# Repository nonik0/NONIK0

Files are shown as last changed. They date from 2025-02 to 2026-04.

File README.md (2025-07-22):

# Nick's Original Name Indicator Knicknack (version 0)

## Overview

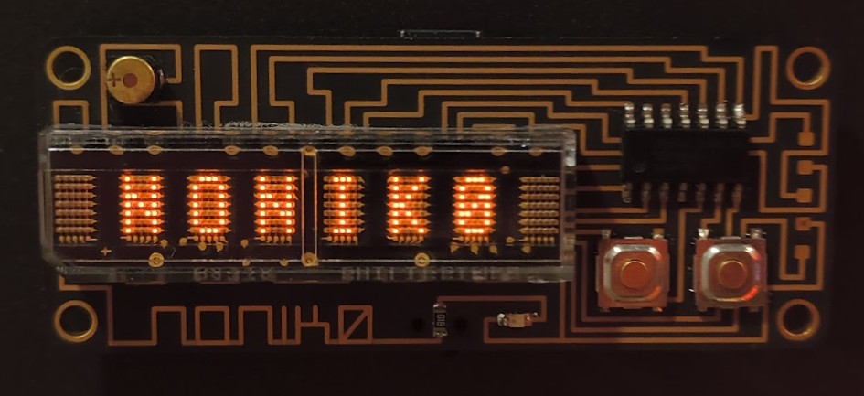
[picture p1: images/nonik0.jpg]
Front of NONIK0 board powered on and showing NONIK0 on display


It's a knicknack to indicate your name with the original design by me, Nick. Version 0. NONIK0 for short! The only version there will ever be. I wanted a name badge to wear sometimes and most other times just use for a fancy LED decoration, and also learn some more Rust. Add in a tad of scope creep and you have also have some games, beeps, and other extras, too. For more detail, I have a [project writeup](https://altonimb.us/nonik0/) where I talk about my process of completing this project start to finish, with more of a focus my experience working with Rust.

### Hardware
The hardware is designed in KiCad 8.0 and all design files are included in the [hardware/kicad8.0](hardware/kicad8.0) directory.

The main hardware components are:
- [HCMS-2914](https://www.broadcom.com/products/leds-and-displays/smart-alphanumeric-displays/serial-interface/hcms-2914) 5x7 dot matrix character display
- [ATtiny1604](https://www.microchip.com/en-us/product/attiny1604) 8-bit MCU
- [CMT-322-65-SMT-TR](https://www.digikey.com/en/products/detail/same-sky-formerly-cui-devices/CMT-322-65-SMT-TR/14682617) Piezo Buzzer 3.2mm x 3.2mm
- 2x [PTS526SMG](https://www.digikey.com/en/products/detail/c-k/PTS526SMG15JSMTR2-LFS/10056629) SPST push buttons

Revision #1:
- Swapped test pads and UPDI pads. The UPDI pads were opposite of the buzzer, which made getting the probe clip to remain clipped over the pads with the buzzer in the way more difficult than it needed to be.
- Added solder jumper to HCMS-291x SEL pin. Can optionally cut jumper to Vcc and solder other side to ground to use external oscillator for display.
- Optimized some routing for power and ground.

Revision #2:
- Fixed I2C pin assignment for external JST-SH connector
- Added piezo driver circuit

### Firmware

The firmware is written in Rust and can be found in the [firmware/rust](firmware/rust) directory. As part of the work, I wrote a new [HCMS-29xx driver](https://github.com/nonik0/hcms-29xx) and forked avr-hal to add a Feather32u4 support, which I used for bootstrapping the HCMS-29xx driver work. There is also an older PlatformIO project targetting the Adafruit Feather in the [firmware/cpp](firmware/cpp) directory.

The firmware is navigated using two buttons. Navigation and control is done with the two push buttons. A short press on the right button is a "next" action and will show the next option in the current context (i.e. the menu or active mode). A short press on the left button depends on the given context, and is either a "previous" action or a "alternate" action. A long press on the right button is an "enter/confirm" action and will enter a mode from the menu or, from within a mode, change the current page or enter a submenu. A long press on the left button will do an "exit" action which exits from a mode to the menu, or exits from a submenu from a mode.

#### Modes

- **Name:** The original inspiration for this project. Displays an 8 character name (or other string). Can enter an edit mode to update the name/value and is persisted in EEPROM.
- **Settings:** Change the current max brightness and max current settings for HCMS-29XX display, in addition to toggling the button tones on or off.
- **Vibes:** Inspired from the prototype's zigzag pattern I used for testing scrolling/smoothness. It reminded me of watching mountains pass by from a train windows, so I added this mode with mountains and clouds with a parallax effect. The speed of the clouds and mountains can be changed with buttons.
- **Sensors:** The first of the scope creep feartures. Uses the ADC and can read various channels includes the internal temperature and references voltage, but primary the external voltage on the external JUST port pins for use as a simple voltmeter. Has a settings page where the various ADC parameter can be alterned, I used this for my own learning and understanding of the ADC parameters when implementing.
- **Random:** A simple mode that has several pages to display random values for use as a decision tool: integer values, dice values, "eight ball" yes/maybe/no values, and random cuisine types.
- **Tunnel** A basic tunnel game where you control a runner that moves up/down with left/right buttons and you try to survive as long as possible as the tunnel shrinks.
- **Traffic** Another basic game where a you control a driver that advances to the right as you avoid other traffic (rectangles) progressing to the left.

## Design Images

<p align="center" width="100%">
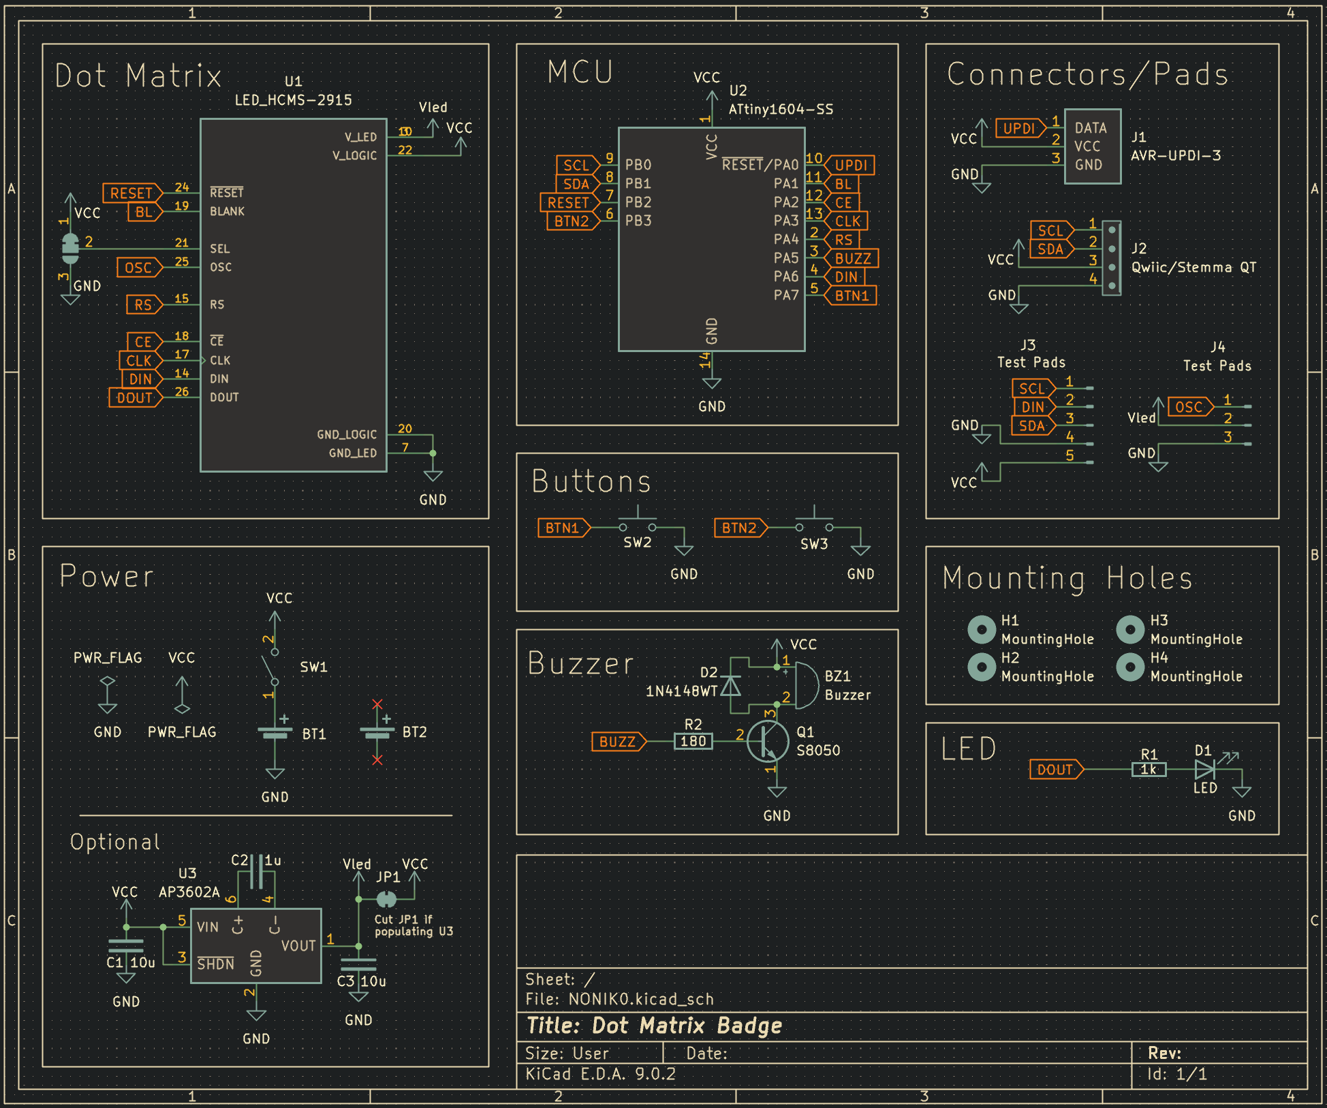
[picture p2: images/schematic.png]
  
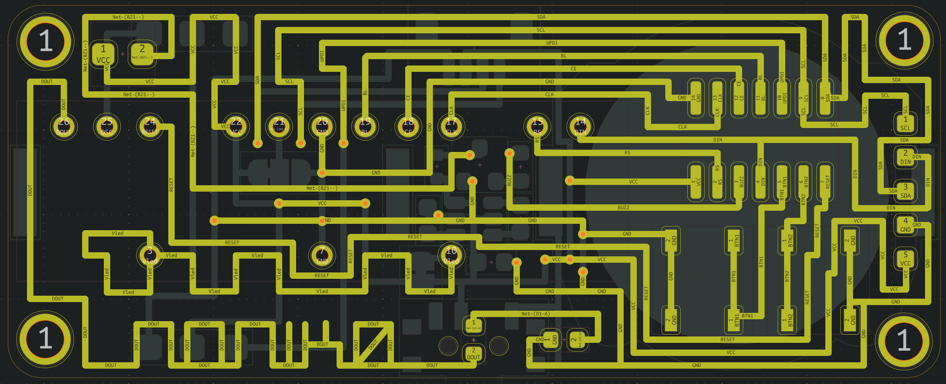
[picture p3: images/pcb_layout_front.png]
  
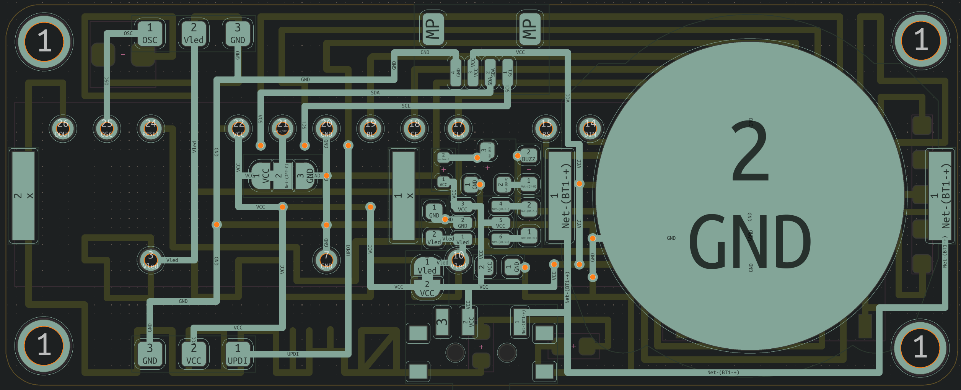
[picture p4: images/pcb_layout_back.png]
  
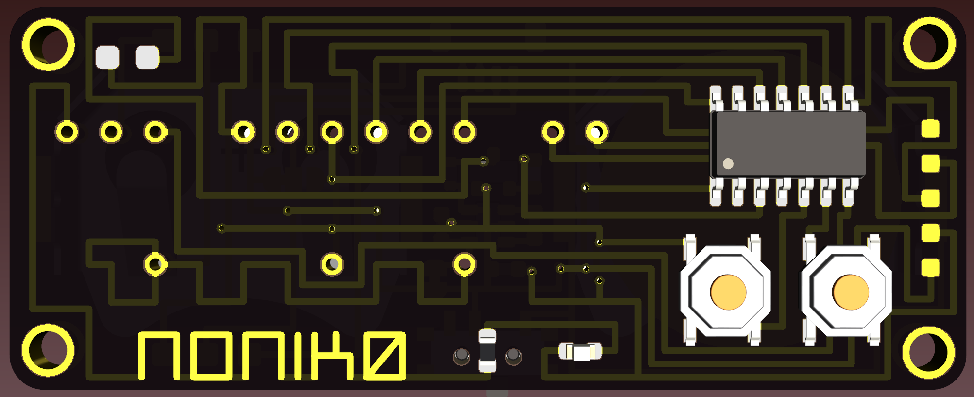
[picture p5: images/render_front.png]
  
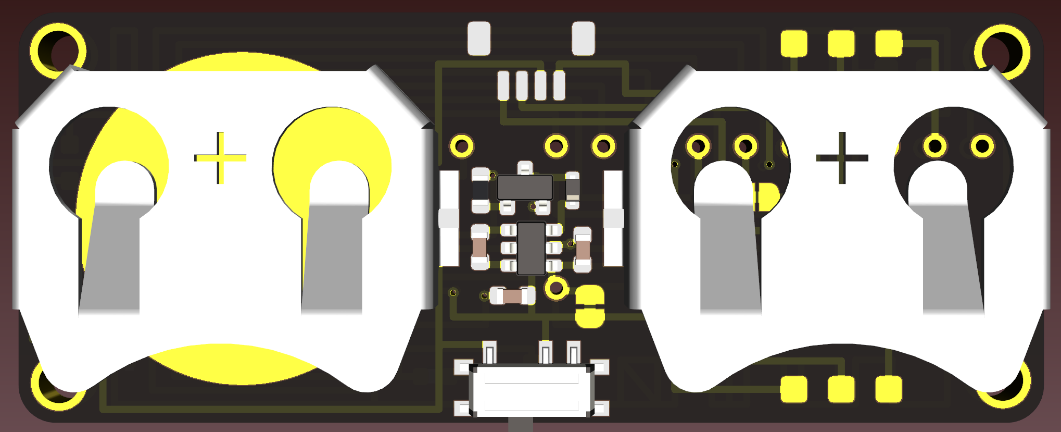
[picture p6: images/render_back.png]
  
</p>

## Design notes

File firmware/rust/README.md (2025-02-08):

NONIK0
==========

Rust project for the _Arduino Leonardo_.

## Build Instructions
1. Install prerequisites as described in the [`avr-hal` README] (`avr-gcc`, `avr-libc`, `avrdude`, [`ravedude`]).

2. Run `cargo build` to build the firmware.

3. Run `cargo run` to flash the firmware to a connected board.  If `ravedude`
   fails to detect your board, check its documentation at
   <https://crates.io/crates/ravedude>.

4. `ravedude` will open a console session after flashing where you can interact
   with the UART console of your board.

[`avr-hal` README]: https://github.com/Rahix/avr-hal#readme
[`ravedude`]: https://crates.io/crates/ravedude

## License
Licensed under either of

 - Apache License, Version 2.0
   ([LICENSE-APACHE](LICENSE-APACHE) or <http://www.apache.org/licenses/LICENSE-2.0>)
 - MIT license
   ([LICENSE-MIT](LICENSE-MIT) or <http://opensource.org/licenses/MIT>)

at your option.

## Contribution
Unless you explicitly state otherwise, any contribution intentionally submitted
for inclusion in the work by you, as defined in the Apache-2.0 license, shall
be dual licensed as above, without any additional terms or conditions.

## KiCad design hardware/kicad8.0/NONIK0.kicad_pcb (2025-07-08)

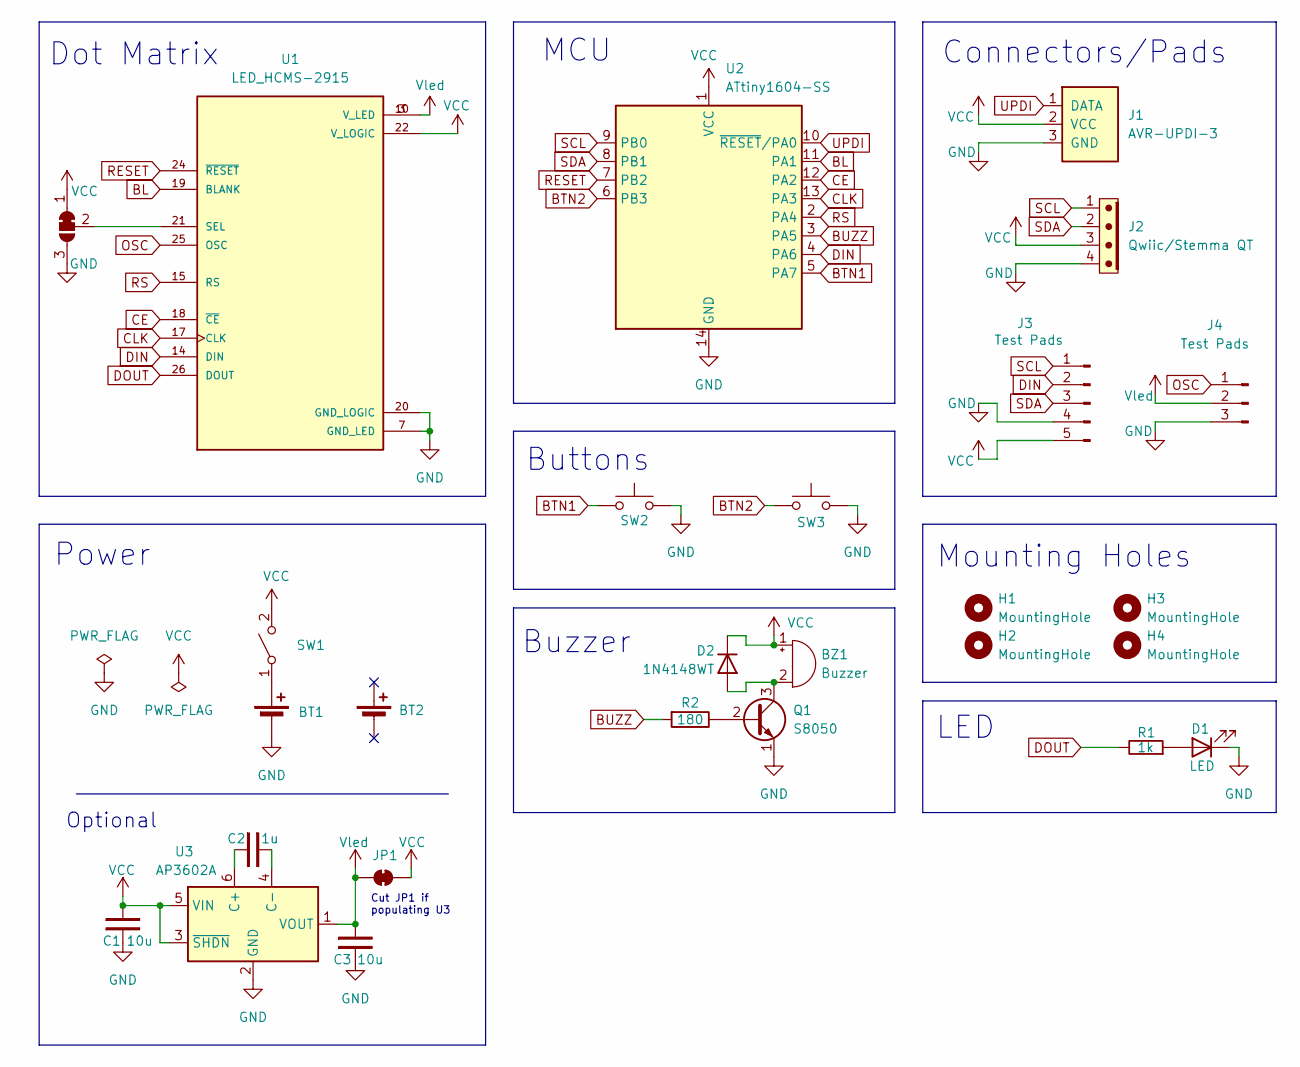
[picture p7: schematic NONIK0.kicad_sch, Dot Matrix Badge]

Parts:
BT1: Battery_Cell; BatteryHolder_Keystone_3034_1x20mm
BT2: Battery_Cell; SpareBatteryHolder_Keystone_3034_1x20mm
BZ1: Buzzer; CMT-322-65-SMT-TR
C1, C3: 10u; C_0603_1608Metric
C2: 1u; C_0603_1608Metric
D1: LED; LED_0603_1608Metric
D2: 1N4148WT; D_SOD-523_NoSilkscreen
H1, H2, H3, H4: MountingHole; MountingHole_Custom
J1: AVR-UPDI-3; Pads_1x3_2.54mm
J2: Qwiic/Stemma QT; JST_SH_4P_No Silkscreen
J3: Test Pads; Pads_1x5_1mm
J4: Test Pads; Pads_1x3_2.54mm
JP1: SolderJumper_2_Bridged; SolderJumper_SmallerFootprint
JP2: SolderJumper_3_Bridged12; SolderJumper-3_P1.3mm_Bridged12_RoundedPad1.0x1.5mm
Q1: S8050; SOT-23-SmallerCourtyard
R1: 1k; R_0603_1608Metric
R2: 180; R_0603_1608Metric
SW1: SW_SPST; SW_SPDT_PCM12
SW2, SW3: SW_Push; SW_SPST_PTS526_JLeads
U1: LED_HCMS-2915; HCMS-291X; PARTREV N/A
U2: ATtiny1604-SS; SOIC-14_3.9x8.7mm_P1.27mm
U3: AP3602A; SOT-23-6_SmallerFootprint

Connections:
BL: U1.19 (BLANK), U2.11 (PA1)
BTN1: SW2.1, U2.5 (PA7)
BTN2: SW3.1, U2.6 (PB3)
BUZZ: R2.2, U2.3 (PA5)
CE: U1.18 (~CE), U2.12 (PA2)
CLK: U1.17 (CLK), U2.13 (PA3)
DIN: J3.2, U1.14 (DIN), U2.4 (PA6)
DOUT: R1.2, U1.26 (DOUT)
GND: BT1.2 (-), C1.1, C3.1, D1.1 (K), J1.3 (GND), J2.4, J3.4, J4.3, JP2.3 (B), Q1.1 (E), SW2.2, SW3.2, U1.7 (GND_LED), U1.20 (GND_LOGIC), U2.14 (GND), U3.2 (GND)
unnamed: BT1.1 (+), SW1.1 (A)
unnamed: BZ1.2 (-), D2.2 (A), Q1.3 (C)
unnamed: D1.2 (A), R1.1
unnamed: JP2.2 (C), U1.21 (SEL)
unnamed: Q1.2 (B), R2.1
unnamed: C2.1, U3.6 (C+)
unnamed: C2.2, U3.4 (C-)
OSC: J4.1, U1.25 (OSC)
RESET: U1.24 (~RESET), U2.7 (PB2)
RS: U1.15 (RS), U2.2 (PA4)
SCL: J2.1, J3.1, U2.9 (PB0)
SDA: J2.2, J3.3, U2.8 (PB1)
UPDI: J1.1 (DATA), U2.10 (~RESET/PA0)
VCC: BZ1.1 (+), C1.2, D2.1 (K), J1.2 (VCC), J2.3, J3.5, JP1.2 (B), JP2.1 (A), SW1.2 (B), U1.22 (V_LOGIC), U2.1 (VCC), U3.3 (~SHDN), U3.5 (VIN)
Vled: C3.2, J4.2, JP1.1 (A), U1.3 (V_LED), U1.10 (V_LED), U3.1 (VOUT)

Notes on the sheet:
Cut JP1 if populating U3
Mounting Holes
LED
Optional
MCU
Buttons
Dot Matrix
Connectors/Pads
Power
Buzzer

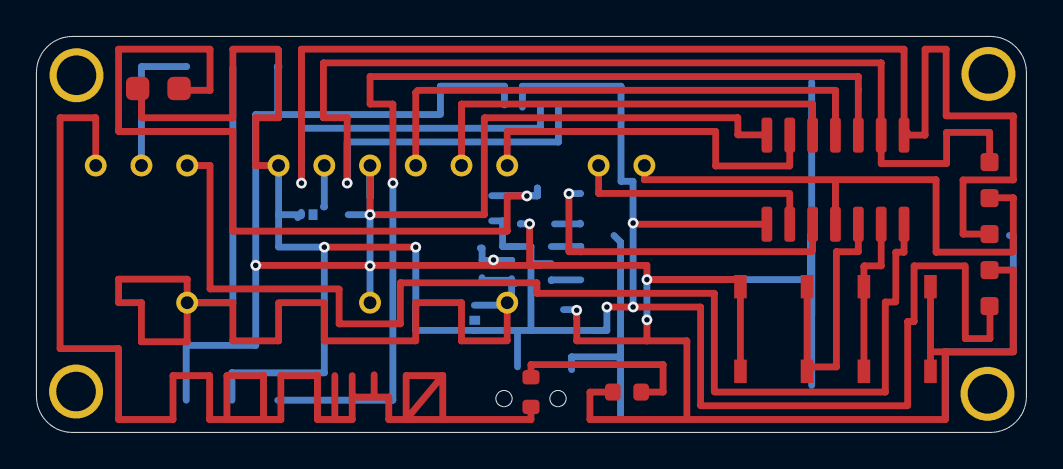
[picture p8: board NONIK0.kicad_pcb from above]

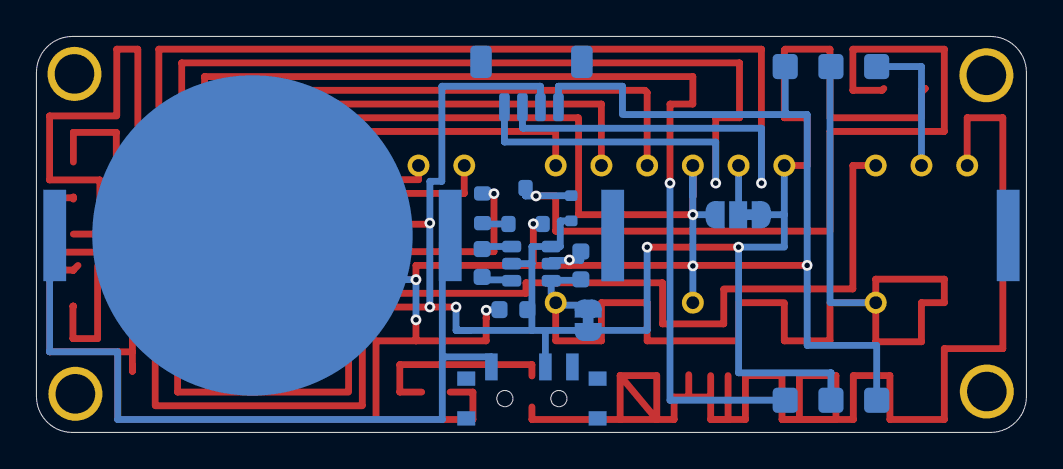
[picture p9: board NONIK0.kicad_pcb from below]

Board: 2 copper layers, 55.0 x 22.0 mm, 27 parts (15 on the bottom side), 24 nets.

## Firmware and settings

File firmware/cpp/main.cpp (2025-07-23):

#include "HCMS39xx.h"

#define NUM_CHARS 8

#ifdef ARDUINO_ARCH_MEGAAVR
#include <Wire.h>
// static pins:
// SEL: HIGH
#define DIN_PIN PIN_PA6 // 4
#define RS_PIN PIN_PA4  // 2
#define CLK_PIN PIN_PA3 // 13
#define CE_PIN PIN_PA2  // 12
#define BL_PIN PIN_PA1  // 11
#define SEL_PIN HCMS39xx::NO_PIN
// #define RESET_PIN PIN_PB0 // 9
#define RESET_PIN PIN_PB2 // 7

#define BTN1_PIN PIN_PA7 // 5
#define BTN2_PIN PIN_PB3 // 6

#define SDA_PIN PIN_PB1 // 8
// #define SCL_PIN PIN_PB2 // 7
#define SCL_PIN PIN_PB0 // 9

#define BUZZ_PIN PIN_PA5 // 3
#endif

#ifdef ARDUINO_AVR_FEATHER32U4
// static pins:
// 2: OSC: NC
// 8: BLANK: GND
// 10: SEL: HIGH
// 12: Reset: HIGH

// pin mappings feather proto:
// top display
// 7 | CE       | SDA/2
// 8 | BLANK    | SCL/3
// 9 | GND      | 5
// 10| SEL      | 6
// 11| Vlogic   | 9
// 12| Reset    | 10
// bottom display
// 1 | Data Out | SCK
// 2 | OSC      | MOSI
// 3 | Vled     | MISO
// 4 | Data In  | RX/0
// 5 | RS       | TX/1
// 6 | CLK      | GND (have to cut connection and route another pin)
#define DIN_PIN 0
#define RS_PIN 1
#define CLK_PIN 11
#define CE_PIN 2
#define BL_PIN 3
#define SEL_PIN 6
#define RESET_PIN 10

#define DOUT_PIN SCK
#define OSC_PIN MOSI

#define VLOGIC_PIN 9
#define VLED_PIN MISO
#define GND_PIN 5
#endif

#if defined(ARDUINO_ARCH_ESP32)
#define DIN_PIN 35
#define RS_PIN 37
#define CLK_PIN 36
#define CE_PIN 34
#define SEL_PIN HCMS39xx::NO_PIN
// missing pins
#endif

HCMS39xx hcms29xx(NUM_CHARS, DIN_PIN, RS_PIN, CLK_PIN, CE_PIN, BL_PIN, SEL_PIN);
uint8_t brightness = 0x0C;
HCMS39xx::DISPLAY_CURRENT current = HCMS39xx::CURRENT_4_0_mA;

void setup()
{
  Serial.begin(9600);

#if defined(RESET_PIN)
  pinMode(RESET_PIN, OUTPUT);
  digitalWrite(RESET_PIN, HIGH);
#endif

#if defined(ARDUINO_ARCH_MEGAAVR)
  Wire.begin();
  pinMode(BTN1_PIN, INPUT_PULLUP);
  pinMode(BTN2_PIN, INPUT_PULLUP);
#endif

#if defined(ARDUINO_AVR_FEATHER32U4)
  // put into high impedance
  pinMode(DOUT_PIN, INPUT);
  pinMode(OSC_PIN, INPUT);
  pinMode(VLOGIC_PIN, INPUT);
  pinMode(GND_PIN, INPUT);
#endif

  hcms29xx.begin();
  hcms29xx.displayUnblank();
  hcms29xx.setIntOsc();
  hcms29xx.setBrightness(brightness);
  hcms29xx.setCurrent(current);

  hcms29xx.print("I2C Scan");
  delay(1000);
}

uint32_t count1 = 0;
uint32_t count2 = 0;
void loop()
{
#if defined(ARDUINO_ARCH_MEGAAVR)
  /*
  if (digitalRead(BTN1_PIN) == LOW)
  {
    tone(BUZZ_PIN, 4000, 500);
    count1 = 0;

    brightness = (brightness + 1) % 16;
    hcms29xx.setBrightness(brightness);
    char buffer[10];
    snprintf(buffer, sizeof(buffer), "BRIGHT%02d", brightness);
    hcms29xx.print(buffer);
    delay(500);
  }
  if (digitalRead(BTN2_PIN) == LOW)
  {
    tone(BUZZ_PIN, 6000, 500);
    count2 = 0;

    if (current == HCMS39xx::CURRENT_4_0_mA)
    {
      current = HCMS39xx::CURRENT_6_4_mA;
      hcms29xx.print("CUR6.4mA");
    }
    else if (current == HCMS39xx::CURRENT_6_4_mA)
    {
      current = HCMS39xx::CURRENT_9_3_mA;
      hcms29xx.print("CUR9.3mA");
    }
    else if (current == HCMS39xx::CURRENT_9_3_mA)
    {
      current = HCMS39xx::CURRENT_12_8_mA;
      hcms29xx.print("CR12.8mA");
    }
    else if (current == HCMS39xx::CURRENT_12_8_mA)
    {
      current = HCMS39xx::CURRENT_4_0_mA;
      hcms29xx.print("CUR4.0mA");
    }
    hcms29xx.setCurrent(current);
    delay(500);
  }
  */
  hcms29xx.clear();
  hcms29xx.print("Scanning");
  delay(1000);

  for (byte address = 1; address < 127; address++)
  {
    Wire.beginTransmission(address);
    byte error = Wire.endTransmission();

    if (error == 0)
    {
      char buffer[10];
      snprintf(buffer, sizeof(buffer), "ACK:0x%02X", address);
      hcms29xx.clear();
      hcms29xx.print(buffer);
      delay(2000);
    }
  }

#else
  count1 = (count1 + 1) % 10000;

  if (random(0, 2) % 2 == 0)
  {
    count2 = (count2 + 1) % 10000;
  }

  // shift count1 4 decimal places to the left
  uint32_t displayNumber = count1 * 10000 + count2;
  hcms29xx.print(displayNumber);
#endif
  delay(5);
}

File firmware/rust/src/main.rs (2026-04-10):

#![no_std]
#![no_main]
#![feature(abi_avr_interrupt)]
#![feature(asm_experimental_arch)]
#![feature(type_alias_impl_trait)]

mod adc;
mod i2c;
mod input;
mod modes;
#[cfg(feature = "debug_panic")]
mod panic;
#[cfg(not(feature = "debug_panic"))]
use panic_halt as _;
mod random;
mod saved_settings;
mod tone;
mod utils;

use avrxmega_hal::eeprom::Eeprom;
use avrxmega_hal::port::{mode::Output, *};
use embedded_hal::delay::DelayNs;
use modes::*;
use random::Rand;

// using until proper ADC HAL implementation
type Adc0 = avrxmega_hal::pac::ADC0;
//type I2C = avrxmega_hal::pac::TWI0;
type Sigrow = avrxmega_hal::pac::SIGROW;
type Vref = avrxmega_hal::pac::VREF;
//type Adc = avrxmega_hal::adc::Adc<CoreClock>;
type CoreClock = avrxmega_hal::clock::MHz10;
type Delay = avrxmega_hal::delay::Delay<CoreClock>;
//type I2c = avrxmega_hal::i2c::I2c<CoreClock>;
#[cfg(feature = "board_v0")]
type Display = hcms_29xx::Hcms29xx<
    NUM_CHARS,
    Pin<Output, PA6>,
    Pin<Output, PA4>,
    Pin<Output, PA3>,
    Pin<Output, PA2>,
    Pin<Output, PA1>,
    hcms_29xx::UnconfiguredPin,
    Pin<Output, PB0>,
>;
#[cfg(not(feature = "board_v0"))]
type Display = hcms_29xx::Hcms29xx<
    NUM_CHARS,
    Pin<Output, PA6>,
    Pin<Output, PA4>,
    Pin<Output, PA3>,
    Pin<Output, PA2>,
    Pin<Output, PA1>,
    hcms_29xx::UnconfiguredPin,
    Pin<Output, PB2>,
>;
type DisplayPeakCurrent = hcms_29xx::PeakCurrent;
type Event = input::InputEvent;
type Setting = saved_settings::Setting;
type SavedSettings = saved_settings::SavedSettings;

// The virtual display size is larger to accomodate the physical gaps between characters.
// The const COLUMN_GAP is the number of "empty" columns between characters and will set
// the NUM_VIRT_COLS value, the virtual "width" of the display. During display
// updates, specific columns are dropped/skipped to create final NUM_COLS-wide display buffer.
const NUM_CHARS: usize = 8;
const NUM_ROWS: usize = hcms_29xx::CHAR_HEIGHT;
const NUM_COLS: usize = hcms_29xx::CHAR_WIDTH * NUM_CHARS;
const NUM_VIRT_COLS: usize = NUM_COLS + (NUM_CHARS - 1) * COLUMN_GAP;
const COLUMN_GAP: usize = 2;

const BASE_DELAY_MS: u32 = 5;

#[avr_device::entry]
fn main() -> ! {
    let dp = avrxmega_hal::Peripherals::take().unwrap();
    let pins = avrxmega_hal::pins!(dp);

    let mut buttons =
        input::Buttons::new(pins.pa7.into_pull_up_input(), pins.pb3.into_pull_up_input());
    let mut delay = Delay::new();

    let mut adc = adc::Adc::new(dp.ADC0, dp.SIGROW, dp.VREF);
    adc.seed_rand();

    #[cfg(not(feature = "no_i2cutils"))]
    let i2c = i2c::I2c::new(
        dp.TWI0,
        pins.pb1.forget_imode(),
        pins.pb0.forget_imode(),
    );

    let eeprom = Eeprom::new(dp.NVMCTRL);
    let settings = saved_settings::SavedSettings::new(eeprom);
    let buzzer = tone::Tone::new(dp.TCB0, pins.pa5.into_output());
   
    let mut display = Display::new(
        pins.pa6.into_output(),
        pins.pa4.into_output(),
        pins.pa3.into_output(),
        pins.pa2.into_output(),
        pins.pa1.into_output(),
        hcms_29xx::UnconfiguredPin,
        #[cfg(feature = "board_v0")]
        pins.pb0.into_output(),
        #[cfg(not(feature = "board_v0"))]
        pins.pb2.into_output(),
    )
    .unwrap();
    display.begin().unwrap();
    display.display_unblank().unwrap();

    let mut context = Context::new(settings);
    let mut peripherals = Peripherals::new(
        adc,
        buzzer,
        display,
        #[cfg(feature = "board_v0")]
        pins.pb1.forget_imode(),
        #[cfg(not(feature = "no_i2cutils"))]
        i2c,
    );

    // TODO: improve, apply saved display settings
    let settings = Settings::new_with_settings(&context.settings);
    settings.apply(&mut peripherals.display);

    // initialize default/saved mode
    let mut mode = Mode::from_context(&context);
    let mut mode_index = context.mode_index();
    loop {
        let event = buttons.update();

        match event {
            // special case to get always get back to menu
            Some(Event::BothHeld) => {
                if !context.is_menu() {
                    context.to_menu();
                }
            }
            // higher/shorter tone on button press
            Some(Event::LeftPressed) | Some(Event::RightPressed) => {
                if context.tone_enabled {
                    peripherals.buzzer.tone(5000, 5);
                }
            }
            // lower/longer tone on button held press
            Some(Event::LeftHeld) | Some(Event::RightHeld) => {
                if context.tone_enabled {
                    peripherals.buzzer.tone(4000, 10);
                }
            }
            _ => {}
        }

        // change mode when requested
        if mode_index != context.mode_index() {
            mode_index = context.mode_index();
            mode = Mode::from_context(&context);
        }

        mode.update(&event, &mut context, &mut peripherals);

        delay.delay_ms(BASE_DELAY_MS);
    }
}

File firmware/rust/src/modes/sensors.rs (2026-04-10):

use super::ModeHandler;
use crate::{
    adc::*, impl_enum_cycle, utils::*, Context, Event, Peripherals, SavedSettings, Setting,
    NUM_CHARS,
};

pub const RESOLUTION_VALUES: [u16; 2] = [10, 8]; // 2^10 - 1, 2^8 - 1
                                                 //pub const SAMPLE_NUMBER_DIVISORS: [u16; 7] = [1, 2, 4, 8, 16, 32, 64];
pub const PRESCALER_VALUES: [u16; 8] = [2, 4, 8, 16, 32, 64, 128, 256];
pub const INIT_DELAY_VALUES: [u16; 6] = [0, 16, 32, 64, 128, 256];
pub const INT_REF_VOLTAGE_STRINGS: [&[u8]; 5] = [b"0.55V", b"1.1V", b"2.5V", b"4.34V", b"1.5V"];
pub const VDD_REF_VOLTAGE_STRING: &[u8] = b"Vdd";
pub const BOOL_STRINGS: [&[u8]; 2] = [b" no", b"yes"];

#[cfg(not(feature = "board_v0"))]
pub const CONTINUITY_BLUE_READING_MASK: u16 = 0x0001;
#[cfg(not(feature = "board_v0"))]
pub const CONTINUITY_YELLOW_READING_MASK: u16 = 0x0002;
#[cfg(not(feature = "board_v0"))]
pub const CONTINUITY_BOTH_READING_MASK: u16 = 0x0003;

#[derive(Clone, Copy)]
pub enum SensorPage {
    AdcChannel(AdcChannel),
    ContinuityTest,
}

impl SensorPage {
    pub fn next(&self) -> Self {
        match self {
            SensorPage::AdcChannel(channel) => {
                let next_channel = channel.next_wrapping();
                if next_channel.to_u8() != 0 {
                    SensorPage::AdcChannel(next_channel)
                } else {
                    SensorPage::ContinuityTest
                }
            }
            SensorPage::ContinuityTest => SensorPage::AdcChannel(AdcChannel::from_u8(0)),
        }
    }
}

impl From<u8> for SensorPage {
    fn from(value: u8) -> Self {
        match value {
            1..=AdcChannel::COUNT => SensorPage::AdcChannel(AdcChannel::from_u8(value - 1)),
            _ => SensorPage::ContinuityTest,
        }
    }
}

impl From<SensorPage> for u8 {
    fn from(value: SensorPage) -> Self {
        match value {
            SensorPage::AdcChannel(channel) => 1 + channel.to_u8(),
            _ => 0,
        }
    }
}

#[allow(dead_code)]
#[derive(Clone, Copy)]
#[repr(u8)]
pub enum SensorSetting {
    Resolution,
    SampleNumber,
    SampCap,
    RefVoltage,
    Prescaler,
    InitDelay,
    SetAsdv,
    SampleDelay,
    SampleLength,
}

impl_enum_cycle!(SensorSetting, 9);

pub struct Sensors {
    cur_page: SensorPage,
    cur_setting: SensorSetting,
    port_init: bool,
    tone_active: u8, // different values for continuity channel
    settings_active: bool,
    // for continuity, >0 is continuity, ==0 is none
    last_reading: u16,
    #[cfg(not(feature = "board_v0"))]
    continuity_channel: bool, // false = blue/sda, true = yellow/scl

    show_raw: bool,
    show_tempf: bool,
}

impl Sensors {
    const DECIMAL_PRECISION: u16 = 2; // X.YY

    pub fn new_with_settings(settings: &SavedSettings) -> Self {
        let saved_page = settings.read_setting_byte(Setting::SensorPage);

        Sensors {
            cur_page: saved_page.into(),
            cur_setting: SensorSetting::Resolution,
            port_init: false,
            tone_active: 0,
            settings_active: false,
            last_reading: 0,
            #[cfg(not(feature = "board_v0"))]
            continuity_channel: false,
            show_raw: false,
            show_tempf: false,
        }
    }

    #[inline(never)]
    fn format_setting(&self, buf: &mut [u8; NUM_CHARS], adc: &AdcSettings) {
        match self.cur_setting {
            SensorSetting::Resolution => format_uint(
                buf,
                b"Res:",
                RESOLUTION_VALUES[adc.resolution as usize],
                0,
                Some(b"b"),
            ),
            SensorSetting::SampleNumber => {
                format_uint(buf, b"Snum:", 1 << (adc.sample_number as u8), 0, None)
            }
            SensorSetting::SampCap => {
                format_buf(buf, b"Scap:", BOOL_STRINGS[adc.samp_cap as usize])
            }
            SensorSetting::RefVoltage => format_buf(
                buf,
                b"Vr:",
                if adc.adc_ref_voltage == AdcReferenceVoltage::INTREF {
                    INT_REF_VOLTAGE_STRINGS[adc.int_ref_voltage as usize]
                } else {
                    VDD_REF_VOLTAGE_STRING
                },
            ),
            SensorSetting::Prescaler => format_uint(
                buf,
                b"Div:",
                PRESCALER_VALUES[adc.prescaler as usize],
                0,
                None,
            ),
            SensorSetting::InitDelay => format_uint(
                buf,
                b"Idly:",
                INIT_DELAY_VALUES[adc.init_delay as usize],
                0,
                None,
            ),
            SensorSetting::SetAsdv => format_buf(buf, b"Asdv:", BOOL_STRINGS[adc.asdv as usize]),
            SensorSetting::SampleDelay => {
                format_uint(buf, b"Sdly:", adc.sample_delay as u16, 0, None)
            }
            SensorSetting::SampleLength => {
                format_uint(buf, b"Slen:", adc.sample_length as u16, 0, None)
            }
        }
    }
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

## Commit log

2025-01-01 just starting both firmware and hardware
    [dot-matrix-badge.kicad_pcb, dot-matrix-badge.kicad_sch]
2025-01-21 progress with hcms driver
2025-01-21 cpp firmware, hardware progress
    [dot-matrix-badge.kicad_pcb, dot-matrix-badge.kicad_sch]
2025-01-23 working driver
2025-02-05 almost done with layout
    [dot-matrix-badge.kicad_pcb, dot-matrix-badge.kicad_sch]
2025-02-06 pcb payout almost complete
    [dot-matrix-badge.kicad_pcb, dot-matrix-badge.kicad_sch]
2025-02-06 99% done
    [dot-matrix-badge.kicad_pcb, dot-matrix-badge.kicad_sch]
2025-02-07 halfway through symbol/footprint cleanup
    [dot-matrix-badge.kicad_pcb, dot-matrix-badge.kicad_sch]
2025-02-07 done with cleanup, making things pretty
    [dot-matrix-badge.kicad_pcb, dot-matrix-badge.kicad_sch]
2025-02-08 images and minor
    [NONIK0.kicad_pcb]
2025-02-09 adding power reg and piezo
    [NONIK0.kicad_pcb, NONIK0.kicad_sch]
2025-02-10 pcb done, pending review
    [NONIK0.kicad_pcb, NONIK0.kicad_sch]
2025-02-10 fit and finish things
    [NONIK0.kicad_pcb, NONIK0.kicad_sch]
2025-02-10 more test pads
    [NONIK0.kicad_pcb, NONIK0.kicad_sch]
2025-02-11 pcb fit and finish
    [NONIK0.kicad_pcb]
2025-02-20 moving hcms driver to crate dep
2025-03-06 revert back to proto for now
    [main.rs]
2025-03-14 buttons impl, removing feather impl
2025-03-14 improve button func
2025-03-17 adding basic adc
2025-03-17 starting utils mode for adc testing
2025-03-18 adc settings ctls untested
2025-03-18 adc settings cleanup
2025-03-19 temp fix and format improvements
    [utils.rs]
2025-03-19 submenu for adc settings
2025-03-20 adc minor fix
2025-03-20 pcb revisions
    [NONIK0.kicad_pcb, NONIK0.kicad_sch]
2025-03-22 vibe refactor, bug fix
    [mod.rs, sensors.rs]
2025-03-25 adding bjt to drive buzzer
    [NONIK0.kicad_pcb, NONIK0.kicad_sch]
2025-03-27 fit and finish
    [NONIK0.kicad_pcb]
2025-05-06 absorbing svdrust update from avr-device
2025-05-06 sensor fixes
2025-05-07 avr-hal reverted back to asm impl for eeprom
    [main.rs]
2025-06-10 refactor sensor mode into folder
2025-06-10 hacky fix for sensors for now
    [main.rs, mod.rs]
2025-06-11 refactor ADC and sensors mode
2025-06-22 pcb fixes, in progress
    [NONIK0.kicad_pcb, NONIK0.kicad_sch]
2025-06-22 pcb fixes
    [NONIK0.kicad_pcb]
2025-06-23 adding flyback diode
    [NONIK0.kicad_pcb, NONIK0.kicad_sch]
2025-07-01 kicad 9
    [NONIK0.kicad_pcb]
2025-07-08 hardware minor
    [NONIK0.kicad_pcb]
2025-07-22 board rev test
2025-07-22 i2c mode boilerplate
2025-07-22 i2c in progress
2025-07-23 fix board_v0
2025-07-23 working i2c scanner
2025-07-23 boilerplate for second i2c util
2025-07-23 i2c client untested
2025-07-23 working i2c client
2025-07-24 i2c testing, chunk issue still
    [i2c.rs, i2c_utils.rs]
2025-07-29 optimize for no chunking, larger i2c buf
2025-07-31 new driver version
2025-12-11 i2c pin config fixes
    [i2c.rs, i2c_utils.rs, main.rs]
2025-12-12 sensors minor fix
2026-04-10 continuity sensor
2026-04-10 dual continuity sensors
2026-04-10 support for v0 exp pin
